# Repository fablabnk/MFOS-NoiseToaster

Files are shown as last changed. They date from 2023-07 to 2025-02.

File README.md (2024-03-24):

# MFOS Noise Toaster

> ##### Forked from *[Sam Zeter](https://github.com/samzeter/noise-toaster)*

## Status

Work in progress -> Revision 0.6.1

## Motivation

My first project to get back to electronics and learn something new along the way.
This repository is for the documentation of my journey to a fully functional analog synthesizer and may help other people to build one too.

This is my first electronics project for a long time and I decided to build the __Music From Outher Space -__ __*Noise Toaster*__,  because of the great documentation and the book 'Make: Analog Synthesizers' by Ray Wilson.

## How to use this repository

This repository contains all the files necessary for building the Noise Toaster, including the synth's PCB.  
If you intend to create your own PCB, simply compress all the files located in the 'PCB/Gerber Files' directory into a .zip file and upload it to the PCB manufacturer of your choice.   
In the directories 'classic design' and 'alternative design' (yet to come!) are all files to build the case of the Noise Toaster.    
For the front panels, I also created PCB designs, which you can upload to a manifacturer. Furthermore, there are CAD files and technical drawings (yet to come!) in the folders.   
The 'src' folder contains additional files which might be helpful.

## Project Structure
.  
│  
└── MFOS-NoiseToaster/  
&ensp;&ensp;&ensp;&ensp;│  
&ensp;&ensp;&ensp;&ensp;├── __'src/'__ &rarr; additional files and images that might be helpful for your own build   
&ensp;&ensp;&ensp;&ensp;├── __'classic design/'__ &rarr; all files to build the classic Noise Toaster case   
&ensp;&ensp;&ensp;&ensp;│&ensp;&ensp;&ensp;&ensp;├── __'CAD/'__  
&ensp;&ensp;&ensp;&ensp;│&ensp;&ensp;&ensp;&ensp;│&ensp;&ensp;&ensp;&ensp;└── '.FCstd' &rarr; FreeCAD files for the build    
&ensp;&ensp;&ensp;&ensp;│&ensp;&ensp;&ensp;&ensp;└── __'front panel/'__  
&ensp;&ensp;&ensp;&ensp;│&ensp;&ensp;&ensp;&ensp;&ensp;&ensp;&ensp;&ensp;&ensp;└── KiCAD files for front panel PCB &rarr; .zip this Geber files for the manufacturer   
&ensp;&ensp;&ensp;&ensp;├── __'PCB/'__   
&ensp;&ensp;&ensp;&ensp;│&ensp;&ensp;&ensp;&ensp;└── __'Gerber Files/'__ &rarr; .zip this directory for upload to the manufacturer  
&ensp;&ensp;&ensp;&ensp;│&ensp;&ensp;&ensp;&ensp;│&ensp;&ensp;&ensp;&ensp;└── *.gbr   
&ensp;&ensp;&ensp;&ensp;│&ensp;&ensp;&ensp;&ensp;└── 'Noise Toaster PCB.kicad_pcb'  
&ensp;&ensp;&ensp;&ensp;│&ensp;&ensp;&ensp;&ensp;└── ... &rarr; all files for the circuit diagram    
&ensp;&ensp;&ensp;&ensp;├── __'Bill of Material/'__   
&ensp;&ensp;&ensp;&ensp;│&ensp;&ensp;&ensp;&ensp;└── 'BoM checklist.md'  
&ensp;&ensp;&ensp;&ensp;│&ensp;&ensp;&ensp;&ensp;└── 'interactive BoM.html'    
&ensp;&ensp;&ensp;&ensp;├── README.md  
&ensp;&ensp;&ensp;&ensp;└── TODO.md  
&ensp;&ensp;&ensp;&ensp;└── licence.md &rarr; CC-BY-NC-SA  

## Usefull links and resources

* [Musik From Outer Space](http://musicfromouterspace.com/)
* [MFOS - Noise Toaster - Dokumentation](http://musicfromouterspace.com/index.php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)
* [Ray Wilson - YouTube Channel](https://www.youtube.com/@Musicfromouterspace)
* [MFOS Noise Toaster Presentation - Video by Ray Wilson](https://www.youtube.com/watch?v=smFKx6gfOd0)
* [Noise Toaster in action - Video by Ray Wilson](https://www.youtube.com/watch?v=qHlyuIe3wuU)
* [Make: Analog Synthesizers by Ray Wilson](https://learning.oreilly.com/library/view/make-analog-synthesizers/9781449356200/)

## For what's left TODO ...

[follow the White Rabbit!](TODO.md)

---


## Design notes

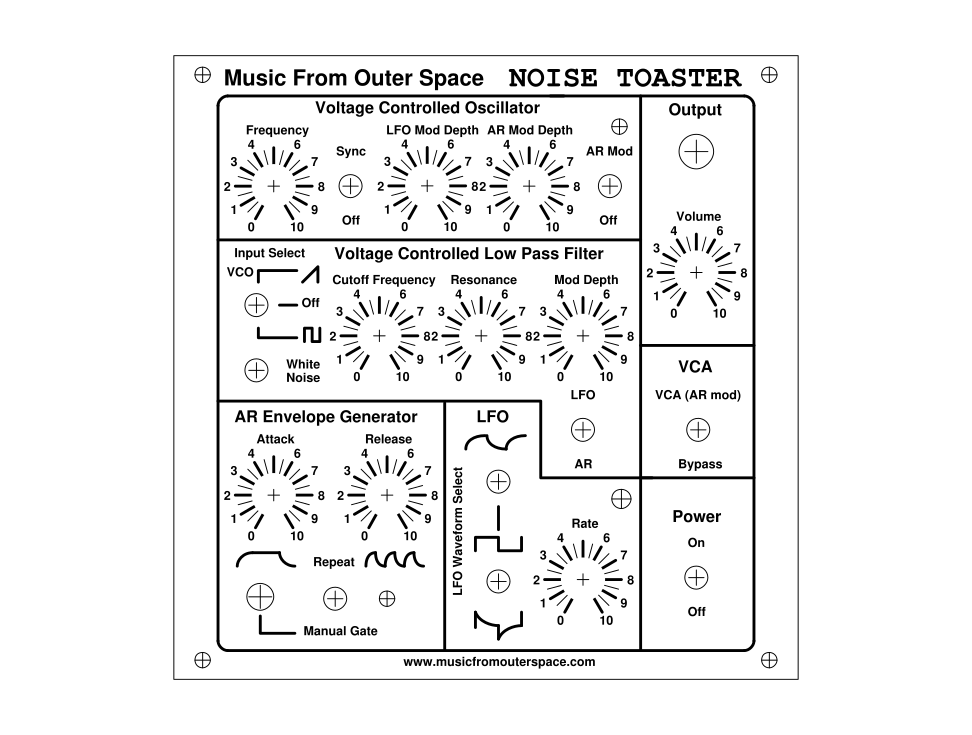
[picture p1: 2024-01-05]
src/classic_panel_design.png

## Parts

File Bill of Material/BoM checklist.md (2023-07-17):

# Bill of Materials for MFOS Noise Toaster

### Active Components
| Check  | Qty | Description | Value/Note | Designators |
|:---:|:---:|:---:|:---:|:---:|
| &#9744;  | 2 | LM324 Quad Low Power Op Amp | 14 pin DIP | U1, U2 |
| &#9744;  | 1 | LM386N4 (or N3) Low Voltage Audio Power Amp | 8 pin DIP | U3 |
| &#9744;  | 1 | 2N3906 PNP Transistor | T092 | Q10 |
| &#9744;  | 4 | 2N5457 N Channel JFET | T092 | Q1, Q7, Q8, Q9 |
| &#9744;  | 5 | 2N3904 NPN Transistor | T092 | Q2, Q3, Q4, Q5, Q6 |
| &#9744;  | 3 | 1N914 High Speed Sw. Diode | D0-35 | D1, D2, D3 |
| &#9744;  | 1 | LED | General Purpose | LED1 |
| &#9744;  | 2 | 14 pin DIP IC Socket | High Reliability |  |
| &#9744;  | 1 | 8 pin DIP IC Socket | High Reliability |  |

### Resistors and Pots
| Check  | Qty | Description | Value/Note | Designators |
|:---:|:---:|:---:|:---:|:---:|
| &#9744;  | 7 | Linear Taper Potentiometer | 100 k&ohm; | R1, R13, R20, R28, R29, R38, R66 |
| &#9744;  | 3 | Linear Taper Potentiometer | 1 M&ohm; | R49, R51, R53 |
| &#9744;  | 3 | Resistor 0,25 W 5 % | 2 M&ohm; | R5, R16, R53 |
| &#9744;  | 1 | Resistor 0,25 W 5 % | 300 k&ohm; | R7 |
| &#9744;  | 1 | Resistor 0,25 W 5 % | 36 k&ohm; | R21 |
| &#9744;  | 1 | Resistor 0,25 W 5 % | 15 k&ohm; | R18 |
| &#9744;  | 2 | Resistor 0,25 W 5 % | 39 k&ohm; | R39, R40 |
| &#9744;  | 3 | Resistor 0,25 W 5 % | 3 k&ohm; | R48, R65, R70 |
| &#9744;  | 5 | Resistor 0,25 W 5 % | 4.7 k&ohm; | R22, R23, R37, R42, R54 |
| &#9744;  | 2 | Resistor 0,25 W 5 % | 4.7 M&ohm; | R33, R35 |
| &#9744;  | 3 | Resistor 0,25 W 5 % | 470 k&ohm; | R10, R19, R41 |
| &#9744;  | 2 | Resistor 0,25 W 5 % | 47 k&ohm; | R27, R36 |
| &#9744;  | 1 | Resistor 0,25 W 5 % | 75 k&ohm; | R2 |
| &#9744;  | 1 | Resistor 0,25 W 5 % | 820 &ohm; | R50 |
| &#9744;  | 1 | Resistor 0,25 W 5 % | 10 &ohm; | R69 |
| &#9744;  | 12 | Resistor 0,25 W 5 % | 100 k&ohm; | R14, R24, R25, R31, R44, R45, R47, R55, R58, R59, R60, R67 |
| &#9744;  | 11 | Resistor 0,25 W 5 % | 10 k&ohm; | R4, R6, R9, R12, R15, R17, R26, R32, R52, R61, R62  |
| &#9744;  | 2 | Resistor 0,25 W 5 % | 150 &ohm; | R63, R64 |
| &#9744;  | 1 | Resistor 0,25 W 5 % | 3 M&ohm; | R34 |
| &#9744;  | 2 | Resistor 0,25 W 5 % | 1 M&ohm; | R8, R46 |
| &#9744;  | 1 | Resistor 0,25 W 5 % | 200 &ohm; | R57 |
| &#9744;  | 2 | Resistor 0,25 W 5 % | 20 k&ohm; | R68, R56 |
| &#9744;  | 1 | Resistor 0,25 W 5 % | 270 k&ohm; | R3 |
| &#9744;  | 1 | Resistor 0,25 W 5 % | 27 k&ohm; | R43 |
| &#9744;  | 1 | Resistor 0,25 W 5 % | 2 k&ohm; | R11 |

### Capacitors
| Check  | Qty | Description | Value/Note | Designators |
|:---:|:---:|:---:|:---:|:---:|
| &#9744;  | 2 | Capacitor Aluminum Bipolar (nonpolarized) | 1 &micro;F | C17, C21 |
| &#9744;  | 3 | Capacitor Ceramic | 0.001 &micro;F / 1 nF | C2, C9, C10 |
| &#9744;  | 1 | Capacitor Ceramic | 0.047 &micro;F / 47 nF | C24 |
| &#9744;  | 8 | Capacitor Ceramic | 0.1 &micro;F / 100 nF | C3, C4, C5, C7, C8, C11, C12, C20 |
| &#9744;  | 1 | Capacitor Ceramic | 100 pF | C1 |
| &#9744;  | 1 | Capacitor Ceramic | 0.01 &micro;F / 10 nF | C6 |
| &#9744;  | 3 | Capacitor Electrolytic | 10 &micro;F | C13, C14, C25 |
| &#9744;  | 2 | Capacitor Electrolytic | 1 &micro;F | C16, C19 |
| &#9744;  | 1 | Capacitor Electrolytic | 4.7 &micro;F | C18 |
| &#9744;  | 1 | Capacitor Electrolytic Radial Lead 0.2" Spacing | 220 &micro;F | C22 |
| &#9744;  | 3 | Capacitor Electrolytic Radial Lead 0.2" Spacing | 470 &micro;F | C15, C23, C26 |

### Hardware and Other Components
| Check  | Qty | Description | Value/Note | Designators |
|:---:|:---:|:---:|:---:|:---:|
| &#9744;  | 1 | Speaker 2 1/4" | 8 &ohm; 1 W | SPK1 |
| &#9744;  | 2 | Switch SPDT (Center Off) Mini Toggle | SPDT C.O. | S3, S6 |
| &#9744;  | 2 | Switch SPDT Mini Toggle | SPDT | S8, S9 |
| &#9744;  | 6 | Switch SPST Mini Toggle | SPST | S1, S2, S4, S5, S7, S11 |
| &#9744;  | 1 | Switch SPST N.O. Pushbutton | SPST | S10 |
| &#9744;  | 1 | Jack 1/4" with NC Switch to Tip |  | J1 |
| &#9744;  | 1 | 9V Alkaline Battery |  | B1 |
| &#9744;  | 1 | 9V Battery Snap Connector |  |  |
| &#9744;  | 1 | 9V Battery Holder |  |  |
| &#9744;  | 1 | Projec Case 7 * 7 * 2" |  |  |
| &#9744;  | 2 | 6-32 1 1/4" Screws |  |  |
| &#9744;  | 4 | 6-32 Screw Nuts |  |  |
| &#9744;  | 4 | 1/4" W x 3/8" L Nylon Spacers |  | 1 |

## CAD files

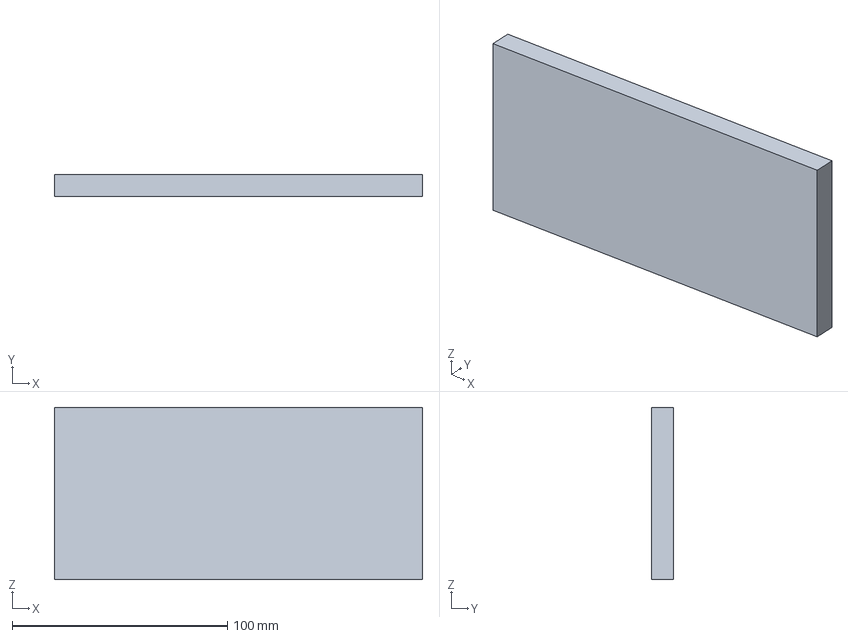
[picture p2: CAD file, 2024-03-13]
classic design/CAD/Side_Panel-A.FCStd
171.1 x 10.0 x 80.0 mm

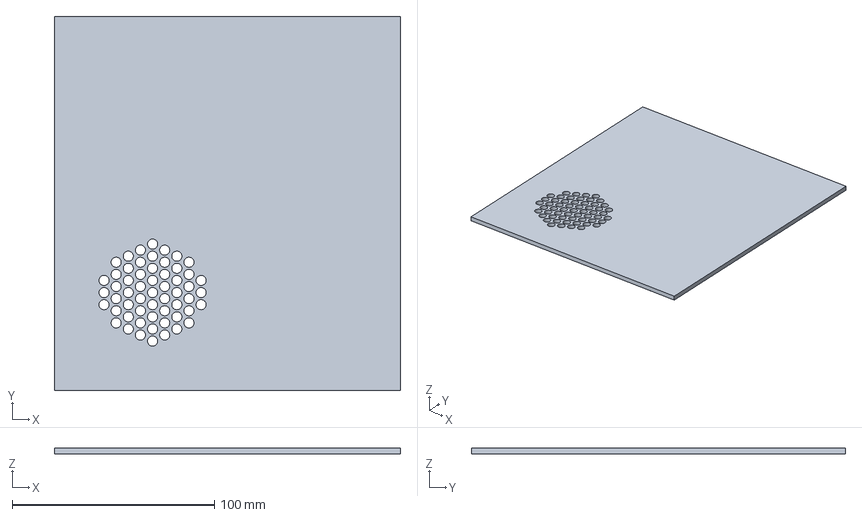
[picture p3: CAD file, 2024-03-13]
classic design/CAD/Back_Panel.FCStd
171.1 x 185.1 x 3.00 mm

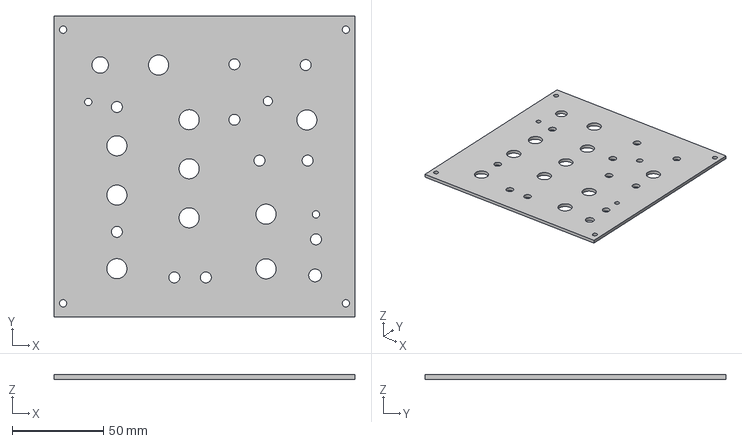
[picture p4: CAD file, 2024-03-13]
classic design/CAD/Front_Panel.FCStd
165.1 x 165.1 x 2.50 mm

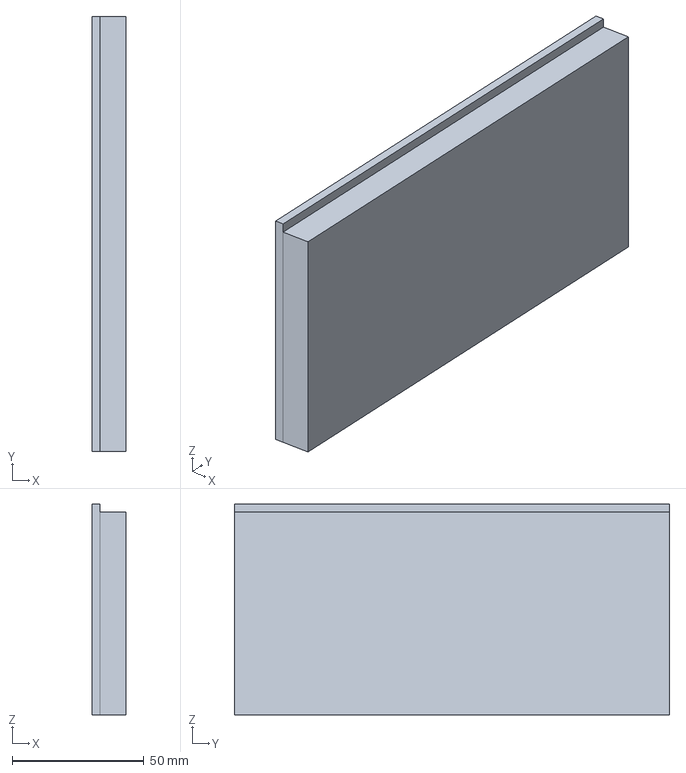
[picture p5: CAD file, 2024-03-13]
classic design/CAD/Side_Panel-B.FCStd
13.0 x 165.1 x 80.0 mm

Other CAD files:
classic design/CAD/Noise_Toaster_Classic.FCStd

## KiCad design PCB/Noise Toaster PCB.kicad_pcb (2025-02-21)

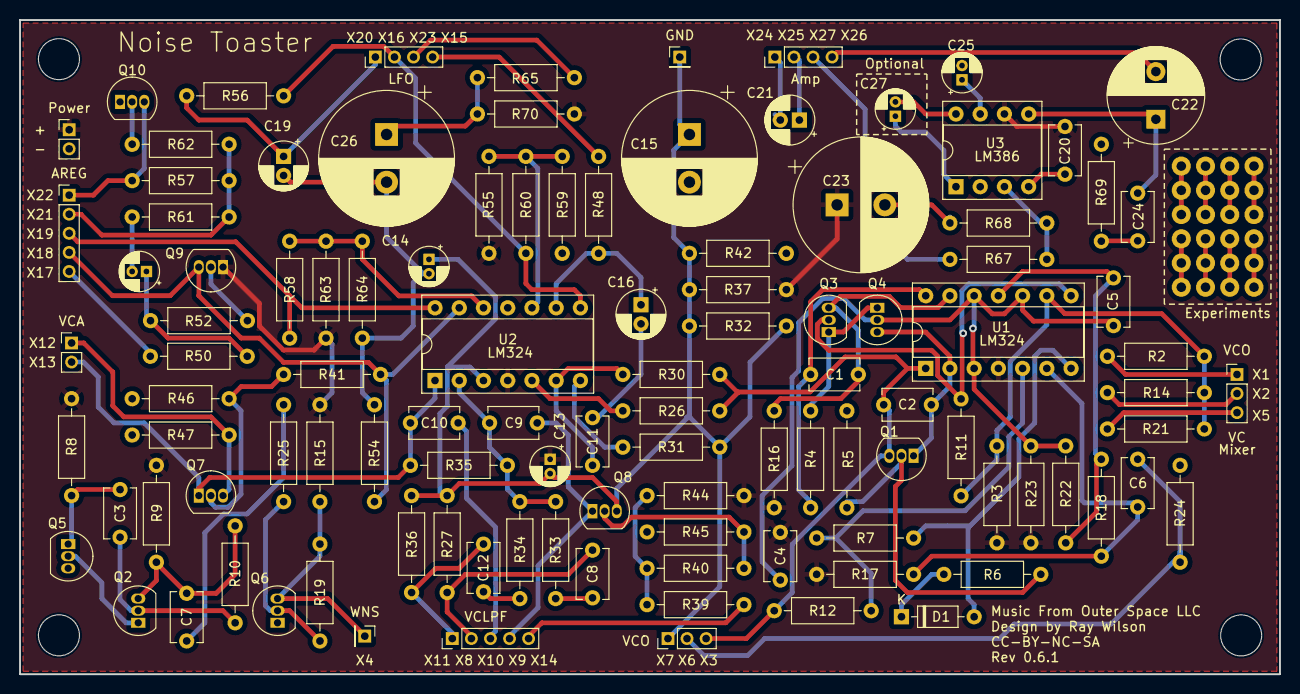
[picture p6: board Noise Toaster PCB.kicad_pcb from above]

Board: 2 copper layers, 132.1 x 68.6 mm, 109 parts (0 on the bottom side), 68 nets.

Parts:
C1: 100 pF; C_Disc_D5.1mm_W3.2mm_P5.00mm
C2, C9, C10: 0.001 uF; C_Disc_D5.1mm_W3.2mm_P5.00mm
C3, C4, C5, C7, C8, C11, C12, C20: 0.1 uF; C_Disc_D5.1mm_W3.2mm_P5.00mm
C6: 0.01 uF; C_Disc_D5.1mm_W3.2mm_P5.00mm
C13, C14, C25, C27: 10 uF; CP_Radial_D4.0mm_P1.50mm
C15, C23, C26: 470 uF; CP_Radial_D14.0mm_P5.00mm
C16, C19, C21: 1 uF; CP_Radial_D5.0mm_P2.00mm
C18: 4.7 uF; CP_Radial_D4.0mm_P1.50mm
C22: 220 uF; CP_Radial_D10.0mm_P5.00mm
C24: 0.047 uF; C_Disc_D5.1mm_W3.2mm_P5.00mm
D1: D; D_DO-35_SOD27_P7.62mm_Horizontal
GND1: GND; PinHeader_1x01_P2.00mm_Vertical
J2: Power; PinHeader_1x02_P2.00mm_Vertical
J3: AREG; PinHeader_1x05_P2.00mm_Vertical
J4: LFO; PinHeader_1x04_P2.00mm_Vertical
J5, J6: VCO; PinHeader_1x03_P2.00mm_Vertical
J7: VCLPF; PinHeader_1x05_P2.00mm_Vertical
J8: VCA; PinHeader_1x02_P2.00mm_Vertical
J9: Amp; PinHeader_1x04_P2.00mm_Vertical
Q1, Q7, Q8, Q9: 2N5457; TO-92_Inline
Q2, Q3, Q4, Q5, Q6: 2N3904; TO-92_Inline
Q10: 2N3906; TO-92_Inline
R2: 75 K; R_Axial_DIN0207_L6.3mm_D2.5mm_P10.16mm_Horizontal
R3: 270 K; R_Axial_DIN0207_L6.3mm_D2.5mm_P10.16mm_Horizontal
R4, R6, R9, R12, R15, R17, R26, R32, R52, R61, R62: 10 K; R_Axial_DIN0207_L6.3mm_D2.5mm_P10.16mm_Horizontal
R5, R16, R30: 2 M; R_Axial_DIN0207_L6.3mm_D2.5mm_P10.16mm_Horizontal
R7: 300 K; R_Axial_DIN0207_L6.3mm_D2.5mm_P10.16mm_Horizontal
R8, R46: 1 M; R_Axial_DIN0207_L6.3mm_D2.5mm_P10.16mm_Horizontal
R10, R19, R41: 470 K; R_Axial_DIN0207_L6.3mm_D2.5mm_P10.16mm_Horizontal
R11: 2 K; R_Axial_DIN0207_L6.3mm_D2.5mm_P10.16mm_Horizontal
R14, R24, R25, R31, R44, R45, R47, R55, R58, R59, R60, R67: 100 K; R_Axial_DIN0207_L6.3mm_D2.5mm_P10.16mm_Horizontal
R18: 15 K; R_Axial_DIN0207_L6.3mm_D2.5mm_P10.16mm_Horizontal
R21: 36 K; R_Axial_DIN0207_L6.3mm_D2.5mm_P10.16mm_Horizontal
R22, R23: 4.7 K; R_Axial_DIN0207_L6.3mm_D2.5mm_P10.16mm_Horizontal
R27, R36: 47 K; R_Axial_DIN0207_L6.3mm_D2.5mm_P10.16mm_Horizontal
R33, R35: 4.7 M; R_Axial_DIN0207_L6.3mm_D2.5mm_P10.16mm_Horizontal
R34: 3 M; R_Axial_DIN0207_L6.3mm_D2.5mm_P10.16mm_Horizontal
R37, R42: 4.7 k; R_Axial_DIN0207_L6.3mm_D2.5mm_P10.16mm_Horizontal
R39, R40: 39 K; R_Axial_DIN0207_L6.3mm_D2.5mm_P10.16mm_Horizontal
R48, R65, R70: 3 K; R_Axial_DIN0207_L6.3mm_D2.5mm_P10.16mm_Horizontal
R50: 820 Ohm; R_Axial_DIN0207_L6.3mm_D2.5mm_P10.16mm_Horizontal
R54: 4,7 K; R_Axial_DIN0207_L6.3mm_D2.5mm_P10.16mm_Horizontal
R56, R68: 20 K; R_Axial_DIN0207_L6.3mm_D2.5mm_P10.16mm_Horizontal
R57: 200 Ohm; R_Axial_DIN0207_L6.3mm_D2.5mm_P10.16mm_Horizontal
R63, R64: 150 K; R_Axial_DIN0207_L6.3mm_D2.5mm_P10.16mm_Horizontal
R69: 10 Ohm; R_Axial_DIN0207_L6.3mm_D2.5mm_P10.16mm_Horizontal
U1, U2: LM324; DIP-14_W7.62mm_Socket
U3: LM386; DIP-8_W7.62mm_Socket
X4: WNS; PinHeader_1x01_P2.00mm_Vertical

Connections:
/AA: C2.1, Q1.1 (D), Q4.3 (C), U1.2 (-)
/ARG: J3.4, Q9.3 (S), R41.1, R54.2, U2.13 (-)
/Attack Release Envelope Generator/X17: J3.5, R50.2
/Attack Release Envelope Generator/X19: J3.3, R58.2, U2.14
/Attack Release Envelope Generator/X21: J3.2, R57.1, R61.2, R62.1
/Attack Release Envelope Generator/X22: J3.1, Q10.3 (C), R57.2
/Audio Amplifier/X24: C21.2, J9.1
/Audio Amplifier/X25: C21.1, J9.2
/Audio Amplifier/X26: C22.2, J9.4
/Audio Amplifier/X27: J9.3, R67.2
/FO: C10.2, J8.2, Q7.1 (D), R35.1, U2.1
/Front Panel/B: J4.2, R56.1, R60.2, U2.8
/Front Panel/X1: J5.1, R2.2
/Front Panel/X2: J5.2, R14.2
/Front Panel/X5: J5.3, R21.2
/Front Panel/X6: C6.1, J6.2, R24.1
/Front Panel/X8: C8.1, J7.2, R27.1
/Front Panel/X9: C9.1, J7.4, Q8.1 (D)
/Front Panel/X10: C10.1, J7.3
/Front Panel/X11: C12.1, J7.1, R36.2
/Front Panel/X12: J8.1, Q7.3 (S), R47.1
/Front Panel/X14: J7.5, R39.1
/Front Panel/X15: J4.4, R48.2
/Front Panel/X20: C19.1, J4.1, R56.2
/Front Panel/X23: J4.3, R65.2
/G2: C4.1, C5.1, Q4.2 (B), R22.1, R23.1, U1.3 (+), U1.10 (+), U1.12 (+)
/RMP: C2.2, J6.3, Q1.3 (S), R12.1, R26.1, R30.1, U1.1
/WNS: Q6.3 (C), R15.2, R19.1, X4.1
B+: C4.2, C13.1, C20.2, C23.1, J2.1, Q9.1 (D), R3.2, R8.1, R9.1, R15.1, R16.2, R17.2, R23.2, R37.1, R44.2, R55.1, R63.1, R70.2, U1.4 (V+), U2.4 (V+), U3.6 (V+)
B-: C5.2, C11.1, C14.2, C15.2, C16.2, C18.2, C19.2, C20.1, C23.2, C25.2, C26.2, J2.2, Q2.1 (E), Q5.2 (B), Q6.1 (E), Q10.1 (E), R5.2, R18.2, R22.2, R24.2, R42.2, R45.1, R46.2, R47.2, R54.1, R59.2, R61.1, R64.1, R68.2, R69.2, U1.11 (V-), U2.11 (V-), U3.2 (-), U3.4 (GND)
GND: C13.2, C14.1, C15.1, GND1.1, J6.1, Q8.3 (S), R27.2, R31.2, R32.1, R32.2, R36.1, R37.2, R42.1, U2.3 (+)
unnamed: C1.2, R4.2, U1.14
unnamed: C7.2, R25.1
unnamed: C8.2, R33.1
unnamed: C12.2, R34.1
unnamed: C18.1, R50.1, R52.1
unnamed: C22.1, C24.1, U3.5
unnamed: C24.2, R69.1
unnamed: C26.1, R65.1, R70.1
unnamed: C27.1, U3.1 (GAIN)
unnamed: C27.2, U3.8 (GAIN)
unnamed: D1.2 (A), R7.2, U1.7
unnamed: D1.1 (K), R6.2
unnamed: Q1.2 (G), R5.1, R6.1
unnamed: C3.2, Q2.2 (B), R10.2
unnamed: C7.1, Q2.3 (C), R9.2, R10.1
unnamed: Q3.2 (B), R11.2, U1.8
unnamed: C1.1, Q3.3 (C), R16.1, U1.13 (-)
unnamed: Q3.1 (E), Q4.1 (E), R4.1
unnamed: C3.1, Q5.1 (E), R8.2
unnamed: Q6.2 (B), R19.2, R25.2
unnamed: Q7.2 (G), R41.2, R46.1
unnamed: Q8.2 (G), R40.2, R45.2
unnamed: Q9.2 (G), R52.2
unnamed: Q10.2 (B), R62.2
unnamed: R31.1, U2.7
unnamed: R39.2, R40.1, R44.1
unnamed: R7.1, R12.2, U1.5 (+)
unnamed: C6.2, R17.1, R18.1, U1.6 (-)
unnamed: R2.1, R3.1, R11.1, R14.1, R21.1, U1.9 (-)
unnamed: C9.2, R33.2, R34.2, R35.2, U2.2 (-)
unnamed: R26.2, U2.5 (+)
unnamed: C11.2, R30.2, U2.6 (-)
unnamed: R55.2, R59.1, R60.1, U2.10 (+)
unnamed: C16.1, R48.1, U2.9 (-)
unnamed: R58.1, R63.2, R64.2, U2.12 (+)
unnamed: R67.1, R68.1, U3.3 (+)
unnamed: C25.1, U3.7 (BYPASS)

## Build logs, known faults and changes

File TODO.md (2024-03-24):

# TODO

* [X] Bill Of Materials
* [ ] dokumentation of the case
	* [X] classic case 
	* [ ] alternative boxes py case for laser cutter
* [ ] dokumentation of the front panel
	* [X] classic front panel design
	* [ ] alternative front panel design
* [X] create pcb files
	* [X] draw schematics
	* [X] check correct wiring
	* [X] check components
	* [X] apply correct footprints
	* [X] create gerber files
* [X] refactor the whole project o_O

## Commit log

2023-07-12 refactored the gerber files
    [mfos_noise_toaster-B_Cu.gbr, mfos_noise_toaster-B_Mask.gbr, mfos_noise_toaster-B_Paste.gbr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]
2023-07-17 added Bills of Materials as .md file
2023-08-07 updated .gitignore with KiCad files
2023-08-21 updated .gitignore file
    [mfos_noise_toaster-B_Cu.gbr, mfos_noise_toaster-B_Mask.gbr, mfos_noise_toaster-B_Paste.gbr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]
2023-08-21 commiting my KiCad schematics
    [Noise Toaster PCB.kicad_pcb, Noise Toaster PCB.kicad_sch, aa.kicad_sch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]
2023-08-24 updated schematics
    [Noise Toaster PCB.kicad_sch, aa.kicad_sch, areg.kicad_sch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]
2023-08-26 cloned sam zeters original repository
    [LFO.kicad_sch, LFO.sch, attack_decay_generator.kicad_sch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]
2023-08-26 try to resole '2 commits behind messsage'
    [LFO.kicad_sch, LFO.sch, attack_decay_generator.kicad_sch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]
2023-08-26 solved issues
    [LFO.sch, attack_decay_generator.sch, audio_amplifier.sch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]
2023-08-26 fixed final gerber location
    [mfos_noise_toaster-B_Cu.gbr, mfos_noise_toaster-B_Mask.gbr, mfos_noise_toaster-B_Paste.gbr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]
2023-08-26 refactored the schematic
    [Noise Toaster PCB.kicad_sch, aa.kicad_sch, areg.kicad_sch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]
2023-09-10 refactored schematics and added front panel
    [Noise Toaster PCB.kicad_sch, aa.kicad_sch, areg.kicad_sch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]
2023-09-10 removed old pcb files
    [LFO.sch, attack_decay_generator.sch, audio_amplifier.sch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]
2023-09-10 color coded wireing and added color legend
    [Noise Toaster PCB.kicad_sch, fp.kicad_sch]
2023-09-10 front panel components excluded from circuit board
    [fp.kicad_sch]
2023-09-10 fixed legend
    [Noise Toaster PCB.kicad_sch]
2023-09-10 wireing and components have been checked
    [Noise Toaster PCB.kicad_sch, aa.kicad_sch, areg.kicad_sch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]
2023-09-12 applied footprints
    [Noise Toaster PCB.kicad_sch, aa.kicad_sch, areg.kicad_sch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]
2023-09-17 placed pards of the pcb properly
    [Noise Toaster PCB.kicad_pcb, Noise Toaster PCB.kicad_sch, aa.kicad_sch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]
2023-09-18 created pcb file
    [Noise Toaster PCB.kicad_pcb]
2023-09-18 created gerber files
    [Noise Toaster PCB-B_Cu.gbr, Noise Toaster PCB-B_Mask.gbr, Noise Toaster PCB-B_Paste.gbr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]
2023-09-18 created interactive BoM
2023-09-27 rerooted some circuit paths
    [Noise Toaster PCB.kicad_pcb]
2023-09-27 updated BoM
2023-09-27 updated gerber files
    [Noise Toaster PCB-B_Cu.gbr, Noise Toaster PCB-B_Mask.gbr, Noise Toaster PCB-B_Paste.gbr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]
2023-10-11 changed the pcb to the original size factor
    [Noise Toaster PCB-B_Cu.gbr, Noise Toaster PCB-B_Mask.gbr, Noise Toaster PCB-B_Paste.gbr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]
2023-10-12 beautified pcb
    [Noise Toaster PCB-B_Cu.gbr, Noise Toaster PCB-B_Mask.gbr, Noise Toaster PCB-B_Paste.gbr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]
2023-10-27 changed header pins to groups
    [Noise Toaster PCB-B_Cu.gbr, Noise Toaster PCB-B_Mask.gbr, Noise Toaster PCB-B_Paste.gbr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]
2023-10-27 updated interactive Bill of Material
    [Noise Toaster PCB.kicad_pcb]
2023-10-28 fixed silkscreen layer
    [Noise Toaster PCB-B_Cu.gbr, Noise Toaster PCB-B_Mask.gbr, Noise Toaster PCB-B_Paste.gbr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]
2023-10-29 fixed minor issues with the pcb
    [Noise Toaster PCB-B_Cu.gbr, Noise Toaster PCB-B_Mask.gbr, Noise Toaster PCB-B_Paste.gbr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]
2023-10-29 updated BoM and README.md
2024-01-05 commit FreeCAD classic Noise Toaster Files
    [Back_Panel.FCStd, Front_Panel.FCStd, Noise_Toaster_Classic.FCStd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]
2024-01-06 finished the classic case design
    [Back_Panel.FCStd, Front_Panel.FCStd, Noise_Toaster_Classic.FCStd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]
2024-01-07 updated case
    [Back_Panel.FCStd, Front_Panel.FCStd, Noise_Toaster_Classic.FCStd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]
2024-03-13 added front panel pcb
    [Back_Panel.FCStd, Front_Panel.FCStd, Noise Toaster PCB.kicad_pcb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]
2024-03-24 finished classic front panel
    [classic.kicad_pcb]
2024-03-24 refactored the project
    [Back_Panel.FCStd, Front_Panel.FCStd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]
2025-02-21 minor revisions to PCB to avoid isolated islands
    [Noise Toaster PCB.kicad_pcb]

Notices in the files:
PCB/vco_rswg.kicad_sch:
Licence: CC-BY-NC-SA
